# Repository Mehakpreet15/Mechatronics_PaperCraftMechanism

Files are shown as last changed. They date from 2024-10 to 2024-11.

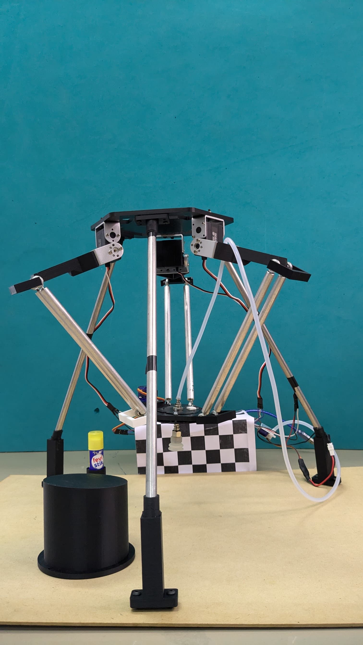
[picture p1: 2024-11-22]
Progress images/Final Model image.jpeg

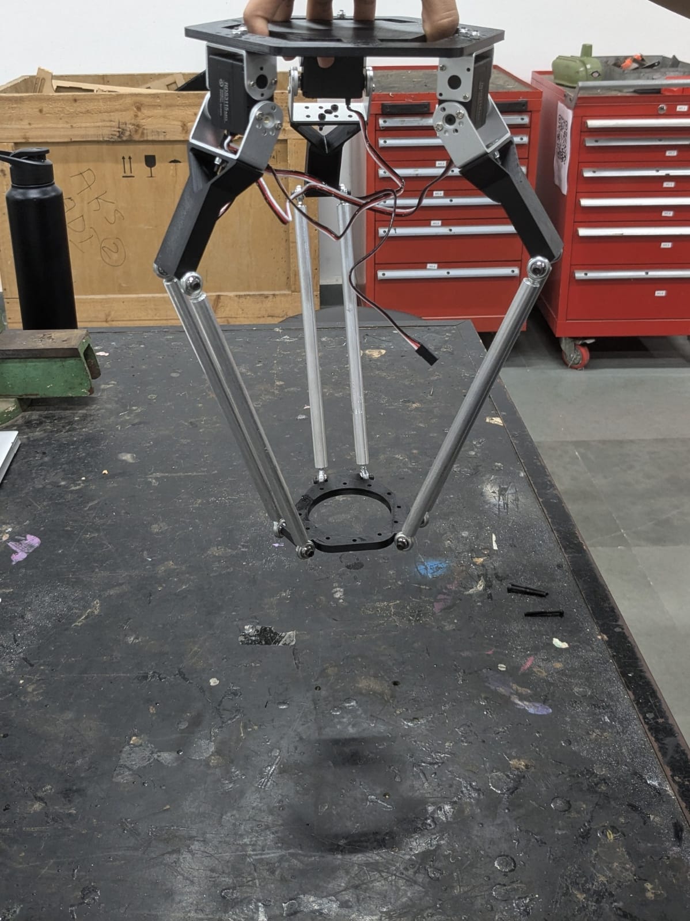
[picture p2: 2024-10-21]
Progress images/progress3.jpg

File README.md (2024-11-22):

# SPAC-R: Suction-Driven Paper Assembly and Crafting Robot

SPAC-R is a Delta robot designed to perform pick-and-place operations using a suction mechanism. It automates the assembly of paper craft flowers by picking pre-cut petals from a designated area, applying glue to them, and assembling them into a complete flower. This repository contains all the necessary resources to recreate and operate SPAC-R, including 3D models, source code, and reference materials.

---

## Features

- **Delta Robot Mechanism**: SPAC-R employs a 4-DOF Delta robot configuration for high-speed, precise movements.
- **Suction Mechanism**: A suction cup mounted on the end effector is used for picking and placing petals.
- **Automated Crafting**: The robot applies glue and assembles petals into a flower autonomously.
- **Inverse Kinematics**: Ensures smooth and accurate motion control of the end effector.
- **Arduino Nano Control**: The system is powered by an Arduino Nano, with code written in C++ for precise control of servo motors and suction mechanisms.

---

## Repository Structure

### 1. **STL Files**
- All 3D-printable components required to build SPAC-R are provided in the `STL_Files` folder.
- Components include:
  - Frame structure
  - End effector
  - Suction mechanism attachments
  - Joint connectors

### 2. **Source Code**
- **`DeltaKinematics.cpp`**: The primary code for controlling SPAC-R's operations.
- **DeltaKinematics.h (`.h`)**: Modularized code for inverse kinematics, servo control, and suction operations.
- Designed to run on an Arduino Nano microcontroller.

### 3. **Prototype Reference Images**
- Find progress images of SPAC-R in the `Progress Images` folder:
  - Progress2.jpg
  - Prototype Image.jpeg
  - 

  - Suction cup of the end effector
  - 

  - progress3.jpg
  - final model image
  - 

### 4. **Reference Videos**
- Demonstrations of SPAC-R in action are located in the `reference Videos` folder:
  - Initial prototype testing
  - End effector rotation
  - Suction assembly in operation
  - Servo movement control
  - Final prototype assembling a flower

---

## Hardware Requirements

### Electronics
- **Controller**: Arduino Nano
- **Servo Motors**:
  - Three for the Delta robot's shafts
  - One micro servo for end effector rotation
- **Suction Mechanism**: Air compressor with battery for powering suction cup
- **Camera**: RPi Camera Module for petal detection (optional)

  ### Circuit Diagram
  -**For Rpi**
  
  -**For Arduino Nano**
  

### 3D-Printed Parts
- STL files are included for all major structural components.

---

## Software Requirements

1. **Arduino IDE**: To upload the control code to the Arduino Nano.
2. **VarSpeedServo Library**: For smooth servo transitions during movement.
3. **C++ Programming Knowledge**: For understanding and customizing the source code if needed.

---

## Assembly Instructions

1. **3D Print Components**: Print the STL files provided in the `STL_Files` folder.
2. **Assemble the Delta Robot**:
   - Follow the reference images in the `Images` folder for guidance.
3. **Install Electronics**:
   - Connect the servo motors and suction mechanism to the Arduino Nano.
   - Attach the camera module (if used).
4. **Upload the Code**:
   - Use Arduino IDE to compile and upload the code from `main.cpp`.
5. **Test the System**:
   - Run initial tests using the `Videos` folder as a guide.

---

## How It Works

1. **Initialization**: SPAC-R moves to the home position and waits for a command.
2. **Pick Operation**: The suction cup picks a petal from the pre-cut paper area.
3. **Glue Application**: The petal is moved to the gluing area.
4. **Assembly**: The petals are sequentially placed to form a complete flower.

---

## List Of Components


## Refernces
- (https://www.thingiverse.com/thing:3465651)
- https://hypertriangle.com/~alex/delta-robot-tutorial/

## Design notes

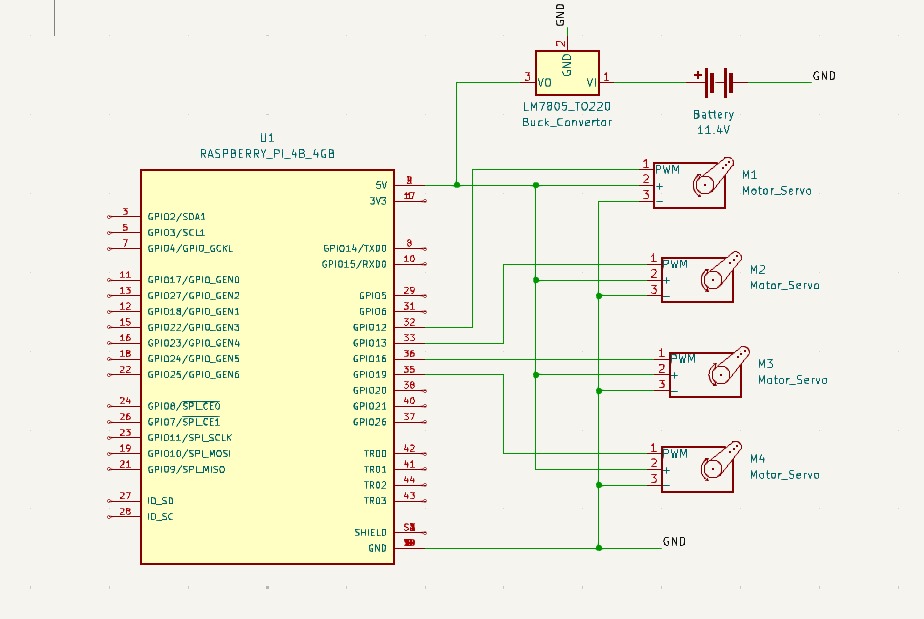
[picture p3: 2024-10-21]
Circuit diagram for Rpi.jpg

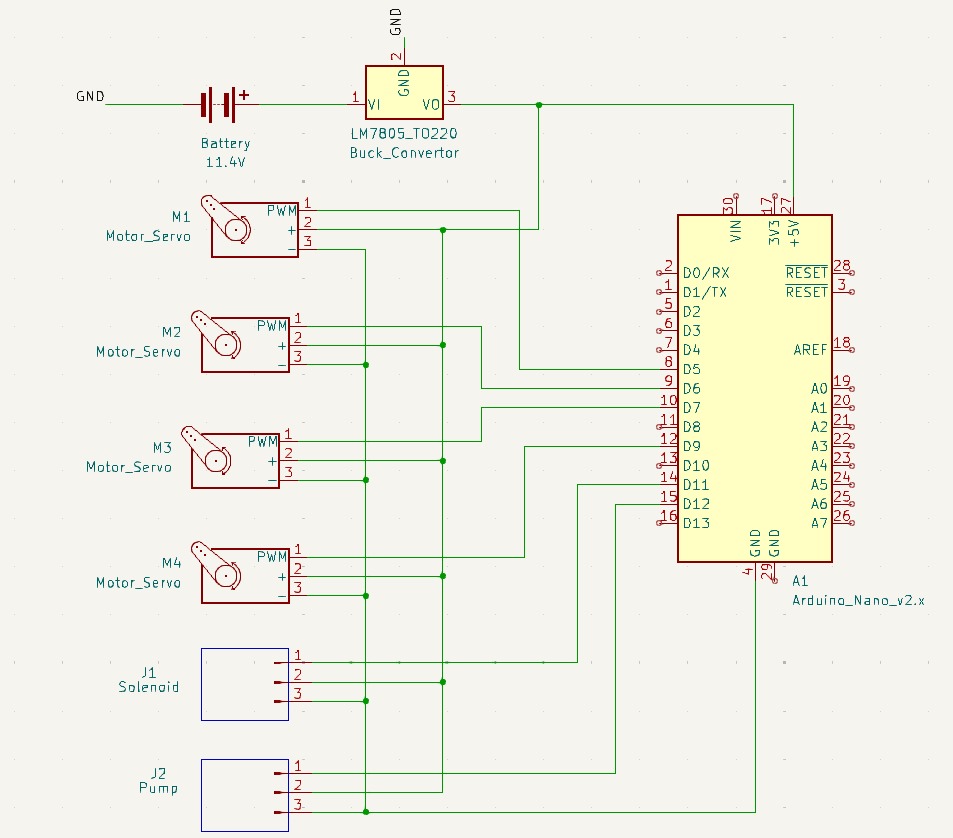
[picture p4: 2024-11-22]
Circuit diagram for Arduino Nano.jpeg

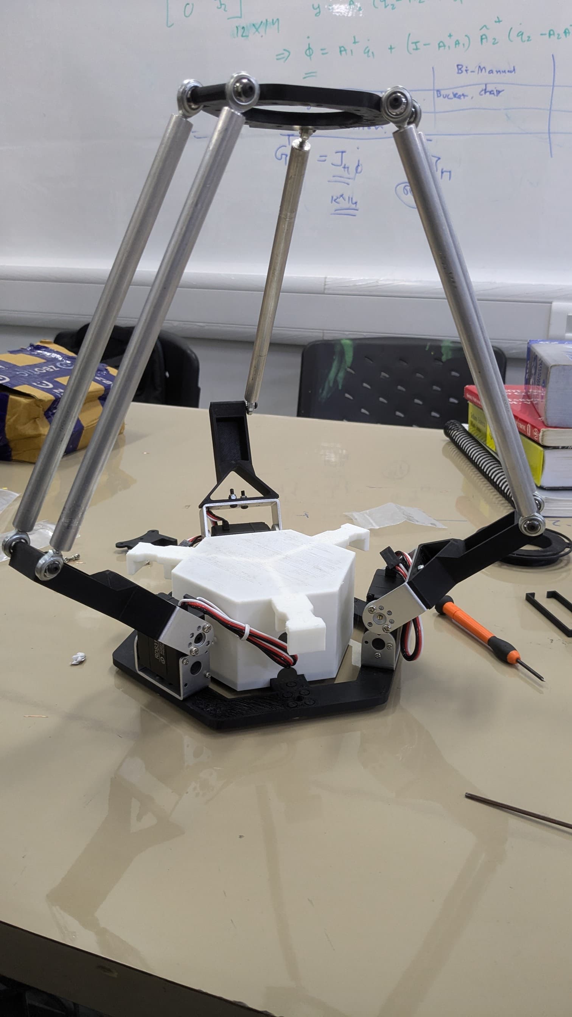
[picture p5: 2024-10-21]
Progress images/Progress2.jpg

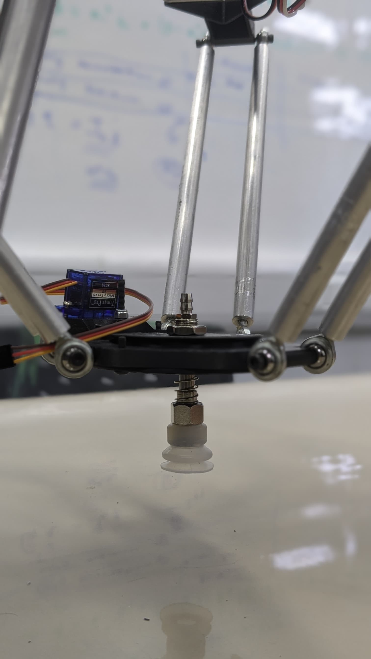
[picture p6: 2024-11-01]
Progress images/Suction cup of the End Effector.jpeg

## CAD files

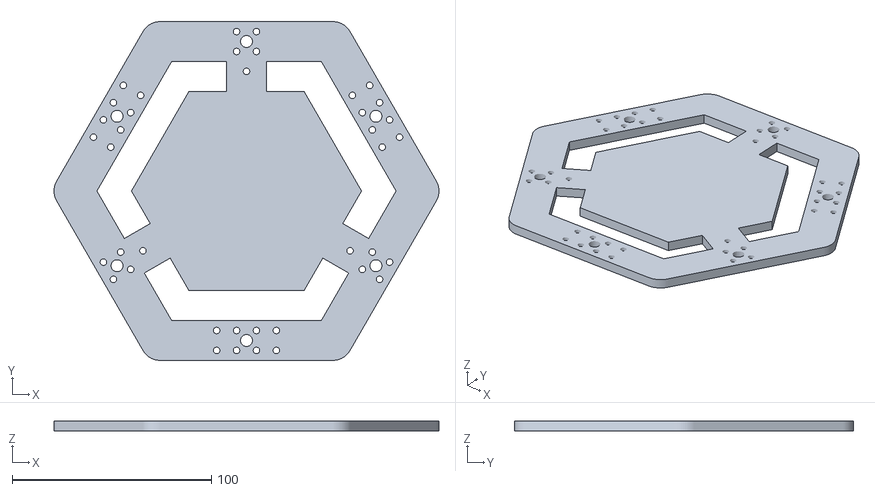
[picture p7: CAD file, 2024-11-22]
stl files/base.stl
193.2 x 170.0 x 5.00

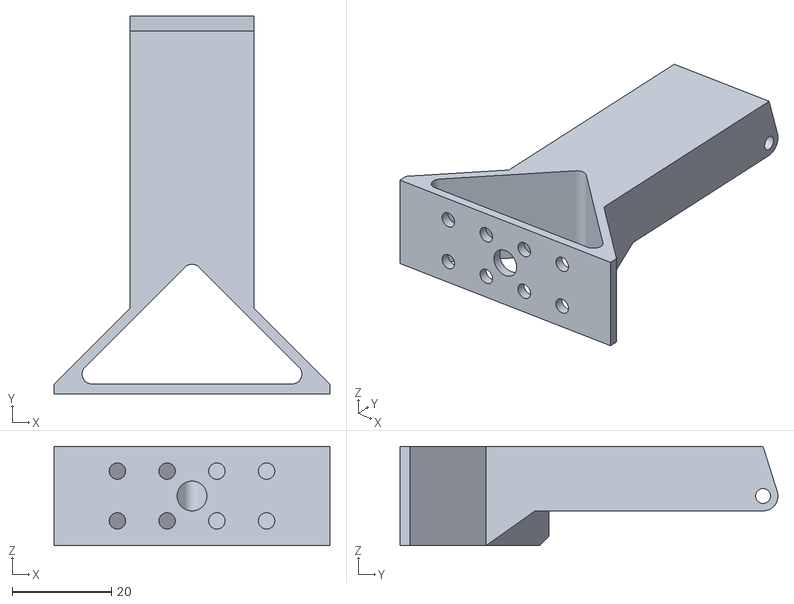
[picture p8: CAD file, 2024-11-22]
stl files/link_1.stl
55.5 x 76.0 x 20.0

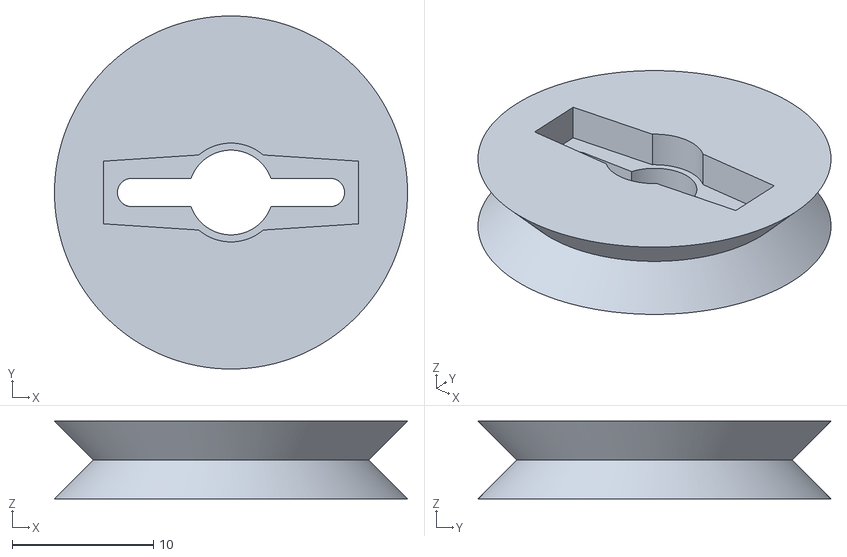
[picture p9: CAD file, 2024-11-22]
stl files/pulley_wheel.stl
25.0 x 25.0 x 5.50

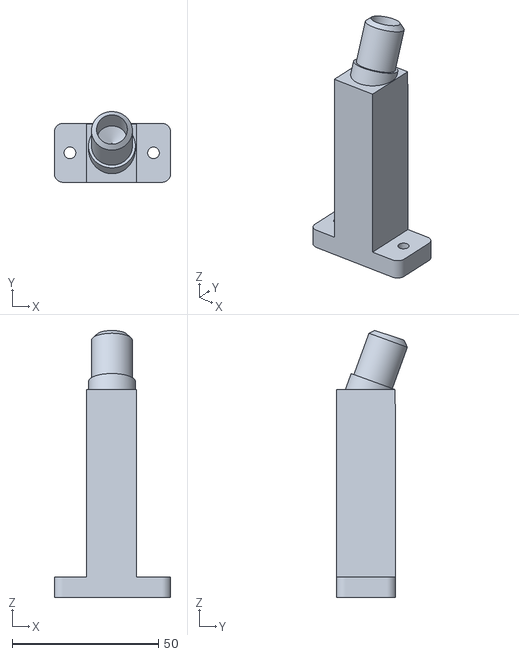
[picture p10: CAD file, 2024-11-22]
stl files/leg mount bottom.stl
39.7 x 24.2 x 91.2

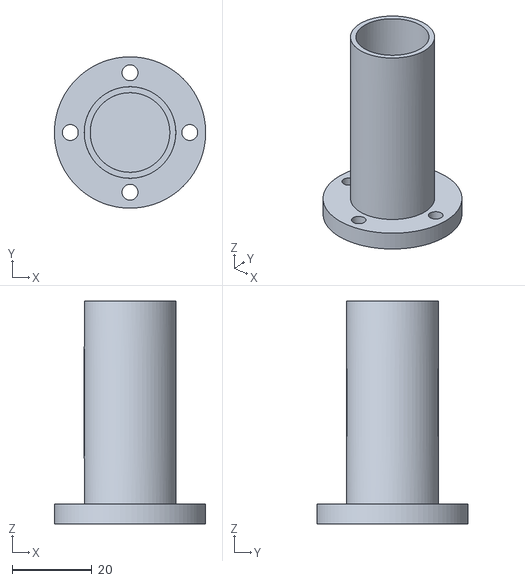
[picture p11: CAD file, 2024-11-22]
stl files/Fevistick Platform (1).stl
38.0 x 38.0 x 56.0

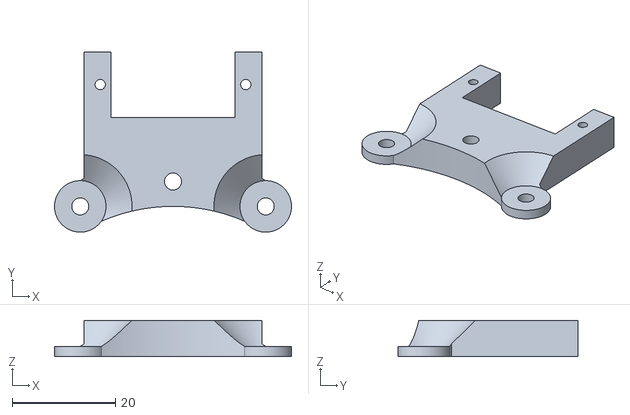
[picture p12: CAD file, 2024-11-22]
stl files/end_effector_servo_mount.stl
46.0 x 35.0 x 7.05

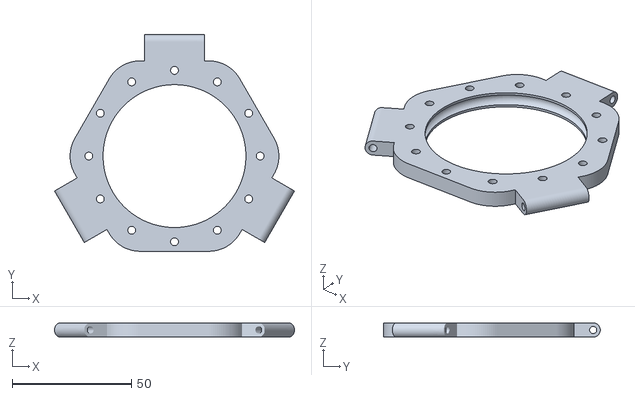
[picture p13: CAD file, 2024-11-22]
stl files/end_effector_platform.stl
100.8 x 91.0 x 6.00

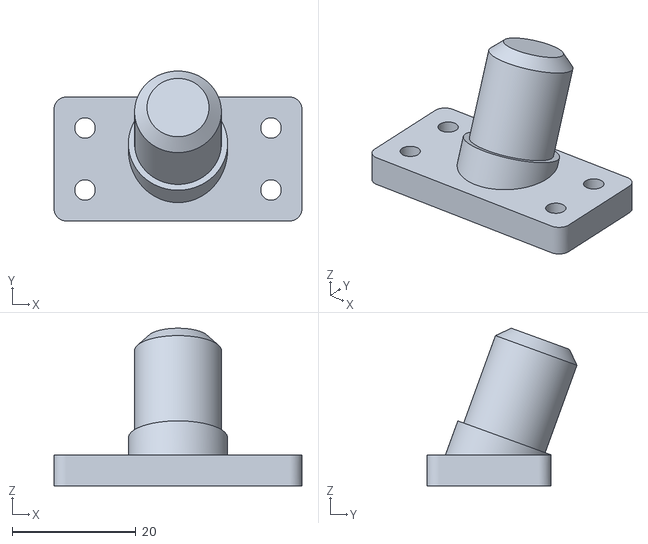
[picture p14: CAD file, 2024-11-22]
stl files/leg_mount.stl
40.0 x 24.2 x 25.4

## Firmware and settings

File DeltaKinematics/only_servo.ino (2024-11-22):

#include <DeltaKinematics.h>
#include <VarSpeedServo.h>

// Delta robot kinematics
DeltaKinematics DK(70, 300, 139, 112);

// Servos for the Delta robot
VarSpeedServo servo1;
VarSpeedServo servo2;
VarSpeedServo servo3;
VarSpeedServo servo4; // Optional for vacuum pump or additional mechanism
VarSpeedServo my_vacuum_pump;

// Define home position
int homePos1 = 30;
int homePos2 = 65;
int homePos3 = 1;
int homePos4 = 1; // Fixed angle for servo4

// Define vacuum pump pin
int vacuum_pump_pin = 12;

void setup()
{
  // Initialize serial communication for debugging
  Serial.begin(115200);

  // Attach the vacuum pump to the vacuum pump control object
  my_vacuum_pump.attach(vacuum_pump_pin);

  // Start with vacuum pump OFF (0 is OFF, 180 is ON)
  my_vacuum_pump.write(0);

  // Attach servos to pins
  servo1.attach(7);
  delay(100);
  servo2.attach(6);
  delay(100);
  servo3.attach(5);
  delay(100);
  servo4.attach(9);
  delay(100);

  // Move servos to initial home position
  moveServos(homePos1, homePos2, homePos3, homePos4);
  delay(2000); // Initial delay to let servos settle
}

void loop()
{
  // Define a series of Cartesian positions for the Delta robot
  float positions[][3] = {
      {0, 0, -300},
      {0, 0, -270},
      {100, 100, -270},
      {50, 50, -250},
      {-50, -50, -250},
      {0, 0, -300} // Return to home
  };

  // Iterate through positions and move servos accordingly
  for (int i = 0; i < 6; i++)
  {
    DK.x = positions[i][0];
    DK.y = positions[i][1];
    DK.z = positions[i][2];
    DK.inverse();

    // Log the Cartesian and servo angles
    Serial.print("Moving to Cartesian position (");
    Serial.print(DK.x);
    Serial.print(", ");
    Serial.print(DK.y);
    Serial.print(", ");
    Serial.print(DK.z);
    Serial.println(")");

    Serial.print("Servo angles: ");
    Serial.print(DK.a);
    Serial.print(", ");
    Serial.print(DK.b);
    Serial.print(", ");
    Serial.println(DK.c);

    // Move the servos to calculated angles
    moveServos(DK.a, DK.b, DK.c, homePos4);

    delay(5000); // Pause for 5 seconds to observe each position

    // Activate/deactivate vacuum pump based on position index
    if (i == 1)
    { // Turn vacuum pump ON at second position
      my_vacuum_pump.write(180);
      Serial.println("Vacuum pump activated.");
    }
    else if (i == 5)
    { // Turn vacuum pump OFF at final position
      my_vacuum_pump.write(0);
      Serial.println("Vacuum pump deactivated.");
    }
  }

  Serial.println("Completed all positions. Repeating...");
  delay(2000); // Wait for 2 seconds before repeating
}

// Function to move servos to specified angles with smooth transition
void moveServos(int angle1, int angle2, int angle3, int angle4)
{
  // Use the VarSpeedServo library to move with speed (90 for smooth transition)
  servo1.write(angle1, 90); // Move servo1 to angle1 at speed 90
  servo2.write(angle2, 90); // Move servo2 to angle2 at speed 90
  servo3.write(angle3, 90); // Move servo3 to angle3 at speed 90
  servo4.write(angle4, 90); // Move servo4 to angle4 at speed 90

  // Print angles for debugging
  Serial.print("Moving to positions - Servo1: ");
  Serial.print(angle1);
  Serial.print(", Servo2: ");
  Serial.print(angle2);
  Serial.print(", Servo3: ");
  Serial.print(angle3);
  Serial.print(", Servo4: ");
  Serial.println(angle4);
}

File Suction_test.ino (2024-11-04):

#include <VarSpeedServo.h>
 
// Create a vacuum pump control object
VarSpeedServo my_vacuum_pump;
 
// Attach vacuump pump to digital pin on the arduino
int vacuum_pump_pin = 10;
 
void setup() {
  // Attach the vacuum pump to the vacuum pump control object
  my_vacuum_pump.attach(vacuum_pump_pin);
 
  // Start with vacuum pump ON (0 is OFF, 180 is ON)
  my_vacuum_pump.write(180);
}
 
// The vacuum suction cup turns ON for five seconds and then
// turns OFF for five seconds.
void loop() {
  my_vacuum_pump.write(180); // Turn the vacuum pump ON (Suction is ON)
  delay(10000); // Wait five seconds
  my_vacuum_pump.write(0); // Turn the vacuum pump OFF (Suction is OFF)
  delay(2000); // Wait five seconds
   
}

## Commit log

2024-09-04 Create Material Required
2024-09-04 Update Material Required
2024-11-04 Rename InShot_20241028_171337686.mp4 to Inverse kinematics demonstration.mp4
2024-11-22 Added STL files folder and other changes
    [Fevistick Platform (1).stl, base.stl, end_effector_platform.stl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]
2024-11-22 Rename WhatsApp Image 2024-11-19 at 11.28.00 PM (1).jpeg to Circuit diagram for Arduino Nano.jpeg
2024-11-22 Rename Circuit diagram.jpg to Circuit diagram for Rpi.jpg
